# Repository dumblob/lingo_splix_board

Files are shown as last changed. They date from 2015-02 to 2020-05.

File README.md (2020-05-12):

# Lingo Splix Board

A brand new deeply ergonomic slim keyboard - HW &amp; SW

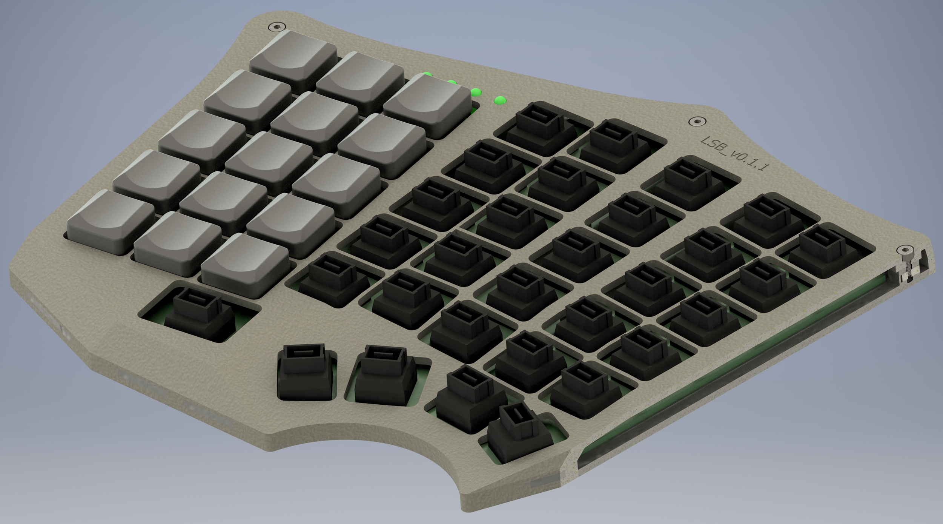
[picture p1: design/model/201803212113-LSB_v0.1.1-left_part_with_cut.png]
left part with a cut


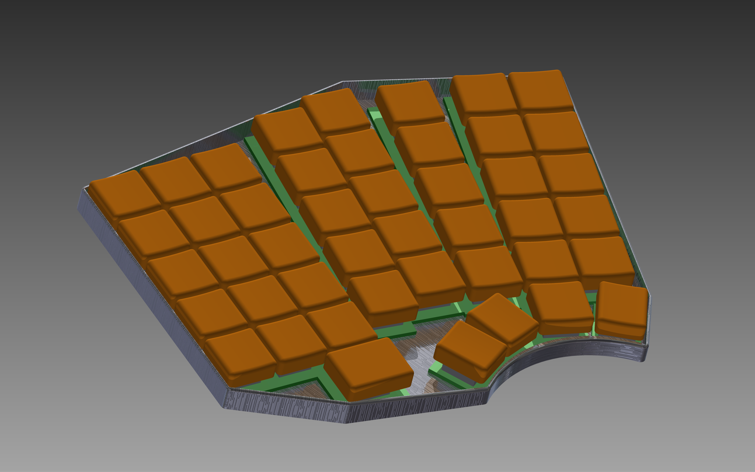
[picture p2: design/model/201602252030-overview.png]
overview_shot


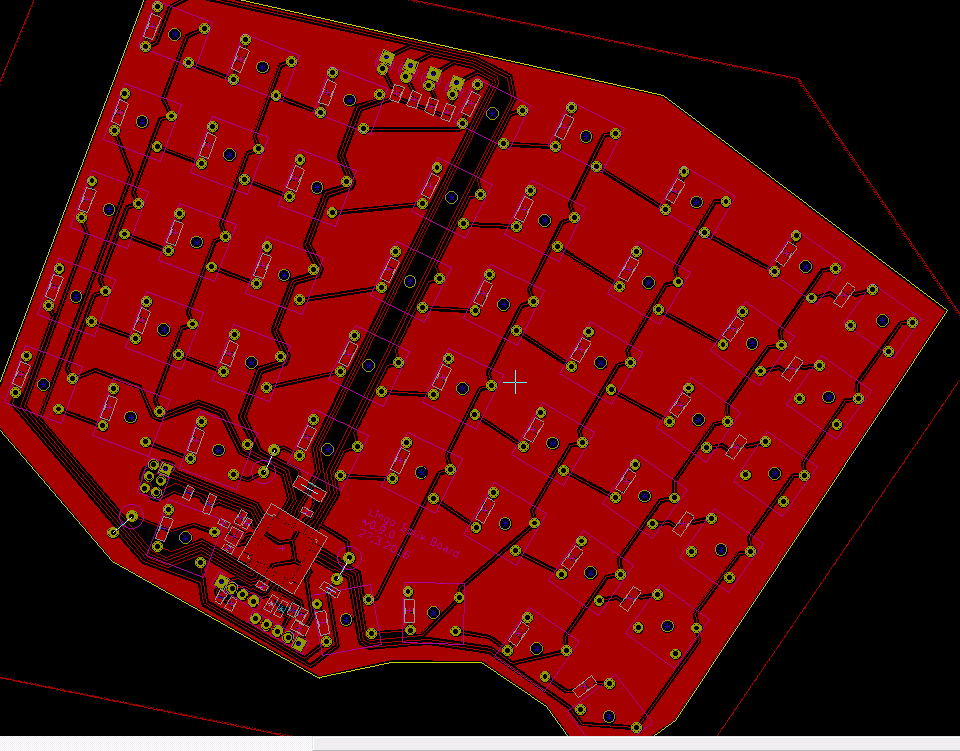
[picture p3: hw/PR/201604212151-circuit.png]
PCB left 201604212151


## Features

1. **Slim low-profile design**
1. **Split into 2 halfs** for outstanding ergonomy
1. **Portable** - easily foldable
1. **USB connection** - use it anywhere
1. [**Modern look**](https://www.youtube.com/watch?v=RVa64frZOLY) - please your heart
1. **Open Source** - never be dependent

<!-- from creators of ULKL -->
<!-- has certification from the Czech Ergonomy Association -->

## Progress

### Done

* design **animation**
    * https://www.youtube.com/watch?v=RVa64frZOLY
* design **sketch**
    * [LSB sketch 201507181700](design/model/201507181700-overview.png )
    * [LSB sketch 201507181701](design/model/201507181701-overview.png )
    * [LSB sketch 201602232051](design/model/201602232051-overview-no_caps.png )
    * [LSB sketch 201602232052](design/model/201602232052-overview.png )
    * [LSB sketch 201602232053](design/model/201602232053-overview.png )
    * [LSB sketch 201602252030](design/model/201602252030-overview.png )
    * [LSB sketch 201803212113 with a cut](design/model/201803212113-LSB_v0.1.1-left_part_with_cut.png )
    * [LSB sketch 201803212113 mirrored with a cut](design/model/201803212113-LSB_v0.1.1-left_part_with_mirrored_cut.png )
* sump **sketch**
    * https://www.youtube.com/watch?v=kU6nasYpbfk
    * [sump sketch left 201602252030](hw/PR/201602252030-sump.png )
* sump **3D print**
    * [sump left 201604081601](hw/PR/201604081601-left_sump_3D_printed.jpg )
    * [sump left 201604081603](hw/PR/201604081603-left_sump_3D_printed.jpg )
* **PCB** circuit scheme
    * [PCB left 20150720170901](hw/PR/20150720170901-screenshot.png )
    * [PCB left 20150720170926](hw/PR/20150720170926-screenshot.png )
    * [PCB left 20160213212414](hw/PR/2016-02-13_212414-screenshot.png )
    * [PCB left 20160228174205](hw/PR/20160228174205-circuit.png )
    * [PCB left 20160228174213](hw/PR/20160228174213-circuit.png )
    * [PCB left 201604212151](hw/PR/201604212151-circuit.png )
    * [PCB left 201604212153](hw/PR/201604212153-circuit.png )
    * [PCB left 201604212154](hw/PR/201604212154-circuit.png )

### TODO

* contact P. Jakoubek, D. Kolibáč, and L. Hejkal regarding the plastic parts of scissor switches (injection moulding into a steel/aluminium mold?)
* choose a better fitting HW license (similar to MIT and CC BY-SA 4.0, but with a notion about HW patents in a way, that anyone using this or derived work can't be sued)
* investigate double-trackpoint/point_stick placement - (un)mountable?, each half it's own and fixed?, 90°-rotated thumb micro-switches on the side?
* marketing (Student Agency - no place for keyboard; ...)
* add numeric keyboard to be successful on market

## Remarks

* use ATmega128A (QFP-64) or ATmega64A (TQFP-64)
* wrong fuse calculation might temporarily "brick" an Atmel uC (see [Engbedded Atmel AVR Fuse Calculator](http://www.engbedded.com/fusecalc/ ))
* *TWI* (Two Wire Interface) on Atmel is *I2C*
* SW USB circuit https://metalab.at/wiki/Metaboard
* 1-wire design guide PDF
* silicon rubber keys are for sale (http://sk.quad-ind.com/silikonove-klavesnice/ , http://www.unipad.cz/index.php/cs/silikonove-klavesnice)
* high-quality plastic manufacturing is affordable (price, time, quality) e.g. at http://www.shapeways.com/ (USA & Europe factories)
* for 3D printing use the most high quality PLA available (see the *arm-netbook* mailing list at phcomp.co.uk): [Faberdashery](http://www.faberdashery.co.uk/tag/pla/ )

## Links for inspiration

* similar keyboard, but done in a megalomaniac way: http://www.key64.org/
* similar keyboard, but done in a yet more megalomaniac way: http://www.keyboard.io/
* similar keyboard, with high switches, but using the same design process as we did (it's unbelievable their design is from 2013, our from 2008, but we didn't share anything :open_mouth:): http://habrahabr.ru/post/177347/
* similar keyboard, but older and from Japan (it's interesting as our design was done completely independently and we discovered this Japan keyboard first in 2020): http://xahlee.info/kbd/Japan_keyboard_layouts.html (look for *jp keyboard layout jis x6004 60014*)
* ZX81 USB kbd: http://blog.tynemouthsoftware.co.uk/2012/02/arduino-based-zx81-usb-keyboard.html
* IBM model M with USB: http://www.schatenseite.de/dulcimer.html?L=2
* IBM model M with USB: http://mg8.org/rump/
* Commodore 64 (C64) USB kbd: http://symlink.dk/projects/c64key/
* Mini Keyboard with Trackpoint: http://geekhack.org/showwiki.php?title=Island:4917&do=comments&page=83
* 3D printed keyboard: http://deskthority.net/workshop-f7/katy-keyboard-or-k80cs-key80-contoured-split-t8524.html
* Apple keyboard mod to NKRO + teensy: http://deskthority.net/viewtopic.php?f=7&t=1067
* SW USB implementation: http://www.obdev.at/products/vusb/index.html
* HW keyboard matrix explained in detail: http://blog.komar.be/how-to-make-a-keyboard-the-matrix/
* how to remove the old yellowish tint: http://retr0bright.wikispaces.com/
* TrackPoint history: https://news.ycombinator.com/item?id=9437780
* TrackPoint creator's collection of human interface devices: http://research.microsoft.com/en-us/um/people/bibuxton/buxtoncollection/default.aspx
* TrackPoint creator's notes about TrackPoint: http://research.microsoft.com/en-us/um/people/bibuxton/buxtoncollection/detail.aspx?id=60
* round plastic circles for index fingers mimicking a gliding TrackPoint

## Wishlist features

* selection from different variants (perhaps configurable)
    * Standard (full-featured big keyboard for power users)
    * Standard Wireless
    * Mini (cut-down version for portability and presentation)
    * Mini Wireless
* both halfs
    * wired (wire spool)
    * wireless (working with Android out of the box)
        * Mini ZigBee / CC2530 Module; HC-06 Arduino Bluetooh Bee; XBee; Bluetooh Bee HC-05 Wireless Bluetooth; Geeetech XBee 2mW Wire Antenna
        * HID for Bluetooth dongles in USB: http://anselm.hoffmeister.be/computer/hidclient/index.html.en
* fixture/handle/hinge to fix both halfs together in a space-saving manner
* backlit
* backlight (adjustable)
* anti-slippery stands (perhaps sucking disks)
* maybe water-proof

## Contributors

* Jiri Pacner (HW design)
* Itchy (HW design feedback)
* Pavel Pacner (3D models, media)
* Jan Pacner (initial idea, initial design, SW)
* *You* (you're more than welcome to join us!)

## Licensing

The following licenses apply if not stated otherwise:

* The SW part is under *MIT* (see `sw/LICENSE`).
* The HW part is under *CC BY-SA 4.0* (see `hw/LICENSE`).
* The rest is under *CC BY-SA 4.0* (see `design/LICENSE`).

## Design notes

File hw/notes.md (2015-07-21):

1) Mrkni na formaty, materialy a veskere dalsi pozadavky pro design desky na http://imall.iteadstudio.com/open-pcb/pcb-prototyping.html (po kliknuti na "add to cart") - budeme to s nejvyssi pravdepodobnosti vyrabet u nich. Mimochodem, az budes pridavat soucastky do vykresu, tak se nejprve mrkni, zdali je nemaji primo na http://imall.iteadstudio.com/electronic-components.html , protoze oni by je tam mohli ihned profesionalne osadit za minimalni priplatek. Tim znatelne zvysujeme sanci na oziveni a snizujeme vlastne cenu, protoze kdybychom kupovali soucastky zvlast, vyjde to nakonec urcite draz. Takovouhle https://openalt.org/led-logo-openaltu/ s nimi mame zkusenost my.

2) Jako cip s nejvyssi pravedpodobnosti pouzijeme bud ATmega64A (TQFP-64) nebo ATmega128A (QFP-64). Dokumentace k fixne danym pinum naleznes primo na strankach Atmelu (ostatni piny, tj. ty, ktere budou pripojene ke spinacum na klavesnici, si muzes navrhnout jak chces). Pouzdra jsou uvedena v zavorkach - tedy TQFP-64 a QFP-64. Prednost ma ATmega128A, protoze to ma dvojnasobne velke oboje dvoje nejdulezitejsi pameti (SRAM a Flash).

2) Budes tam muset zakomponovat obvody pro softwarove USB, konkretne https://metalab.at/wiki/Metaboard .

3) Urcite zacni s https://github.com/geekhack-org/kicad-library - hosi z Geekhacku na tom makaji jiz mnoho let. Take mrkni na "Why not use a Teensy" na http://www.ladyada.net/products/atmega32u4breakout/ , abys na takovehle "prkotiny" pri navrhu myslel. Kdyby te to kresleni fakt chytlo, tak pro inspiraci urcite doporucuji Adafruit https://learn.adafruit.com/ a jejich clanky/navody na pouziti a vyrobu jejich produktu.

4) Kazda polovina klavesnice musi pocitat s 15 GPIO piny - tzn., nelze pouzit "hloupe zapojeni podle radku a sloupcu", nybrz je nutno tlacitka zapojit do ctvercove matice (plus minus jeden radek/sloupec v pripade licheho cisla jako napr. 15=7+8), aby se setrilo mnozstvi GPIO pinu.

5) Nezapomenout na nejake LED kontrolky vyjma CapsLock, tedy zbyva pouze Pause, NumLock a mozna Fn. Lze je umistit kamkoliv, ale je pekne je mit "na ocich" - vyhnul bych se umistovani primo ke klavesam, protoze pokud si na klavesnici namapuji jiny layout, tak su v haji). Kazda LED ma vlastni GPIO, ale lze je "multiplexovat" pres opacna napeti pomoci Charlieplexing (viz wikipedia) - jak to navrhnes je na tobe (s napetim a odberem by nemel byt problem - kdyztak zapoj kazdou ledku do vlastniho portu [PORTA, PORTB, PORTC, PORTD...], protoze kazdy port byva napajeny zvlast, takze piny na jednom portu maji spolecny zdroj a tedy v pripade velkeho proudu pres piny na jednom portu lze odpalit cely port, tzn. vsechny piny - viz. blokovy diagram v dokumentaci). Pro jistotu ale spocitej, kolik ledek muzes na ten tvuj obvod maximalne zapojit a rozsvitit naraz (tj. nejhorsi pripad) a pokud se to bude blizit maximalnimu proudu skrze MCU (microcontroller unit, tedy Atmega), tak radeji pred kazdou ledku dej tranzistor, ktery ji bude pouze zapinat a privadet k ni napeti zvlast z nejakeho externiho spolecneho zdroje (coz bude USB - viz. specifikace).

6) Premyslet nad umistenim trackpointu (byvaji docela objemne a podstavce dost vysoke :cry:). Kolik bude potreba dratu/cesticek pro kazdy trackpoint?

Jinak take muzes nahodne udelat nejake video z toho jak kreslis (klidne i s komentarem - i kdyz nebude anglicky, tak je vitany), aby pote bylo co vystavovat (vsak vis, ze bez obrazku a videa dneska projekt proste neexistuje :( ).

Jednou z mych prvnich myslenek bylo, abys pri navrhu nezapomnel, ze obe poloviny te klavesnice budou muset byt necim propojeny (a tedy kazda mit v sobe vlastni cip - jedna z nich muze byt s vyrazne slabsim cipem, ale ja bych klidne na obe dal ten samy a ty 3 dolary rozdilu moc neresil; ani spotrebu zatim moc neresime :) ) - minimum jsou dva kabely(pro 1-wire protokol s power over line - napr. MicroLAN), kdy datovy kabel je pripojeny na jeden GPIO a k tomu zvenci pres nejaky maly obvudek (minimalne diodu a nejaky rezistor bych tipnul) k tomu datovem pripojis i napajeni a pak pridas druhy kabel, coz je zem. Ale radeji tam navrhni rovnou ctyri kabely pro I2C - tzn. dva kabely pripojene na TWI piny z te Atmegy (tusim pres pull-up rezistory - ale projdi dokumentaci - treba budou uz v cipu a na desce by byly zbytecne) a pak samostatne napajeni a posledni zase zem.

K tomuto vsemu najdes schemata na netu - hledej Atmega nebo AVR - vetsina navodu na obvody je univerzalnich pro jakoukoliv Atmegu.

vim: set wrap:

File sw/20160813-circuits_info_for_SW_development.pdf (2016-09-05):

–
–

–

Shrnuti zapojeni pro programatora:

zakladni info:

na hlavni casti (prava cast) klavesnice je pouzita Atmega 16A druha cast obsahuje Atmegu 8

nastaveni mikrokontroleru:

vnitrni piny nastavit jako input (vyuziti vnitrnich pull-up jako omezeni sumu)

rozlozeni pinu Atmega 16A:

1 - MOSI
2 - MISO
3 - SCK
4 - RST
5 - +5V
6 - GND
7 - crystal
8 - crystal
9 - not connected
10 - not connected
11 - not connected
12 - key input
13 - key input
14 - key input
15 - key input
16 - key input
17 - +5V
18 - GND
19 - SCL
20 - SDA
21 - USB data +
22 - USB data -
23 - not connected
24 - not connected
25 - not connected
26 - not connected
27 - +5V
28 - GND
29 - not connected
30 - key output
31 - key output
32 - key output
33 - key output

34 - key output
35 - key input
36 - LED 1
37 - LED 2
38 - +5V
39 - GND
40 - LED 3
41 - LED 4
42 - key output
43 - key output
44 - key output

rozlozeni pinu Atmega 8:

1 - key output
2 - not connected
3 - GND
4 - +5V
5 - GND
6 - +5V
7 - crystal
8 - crystal
9 - key input
10 - key input
11 - key input
12 - key input
13 - key input
14 - key output
15 - MOSI
16 - MISO
17 - SCK
18 - +5V
19 - not connected
20 - not connected
21 - GND
22 - key output
23 - key output
24 - key output
25 - key output
26 - not connected
27 - SDA
28 - SCL
29 - RST
30 - key input
31 - key output
32 - key output

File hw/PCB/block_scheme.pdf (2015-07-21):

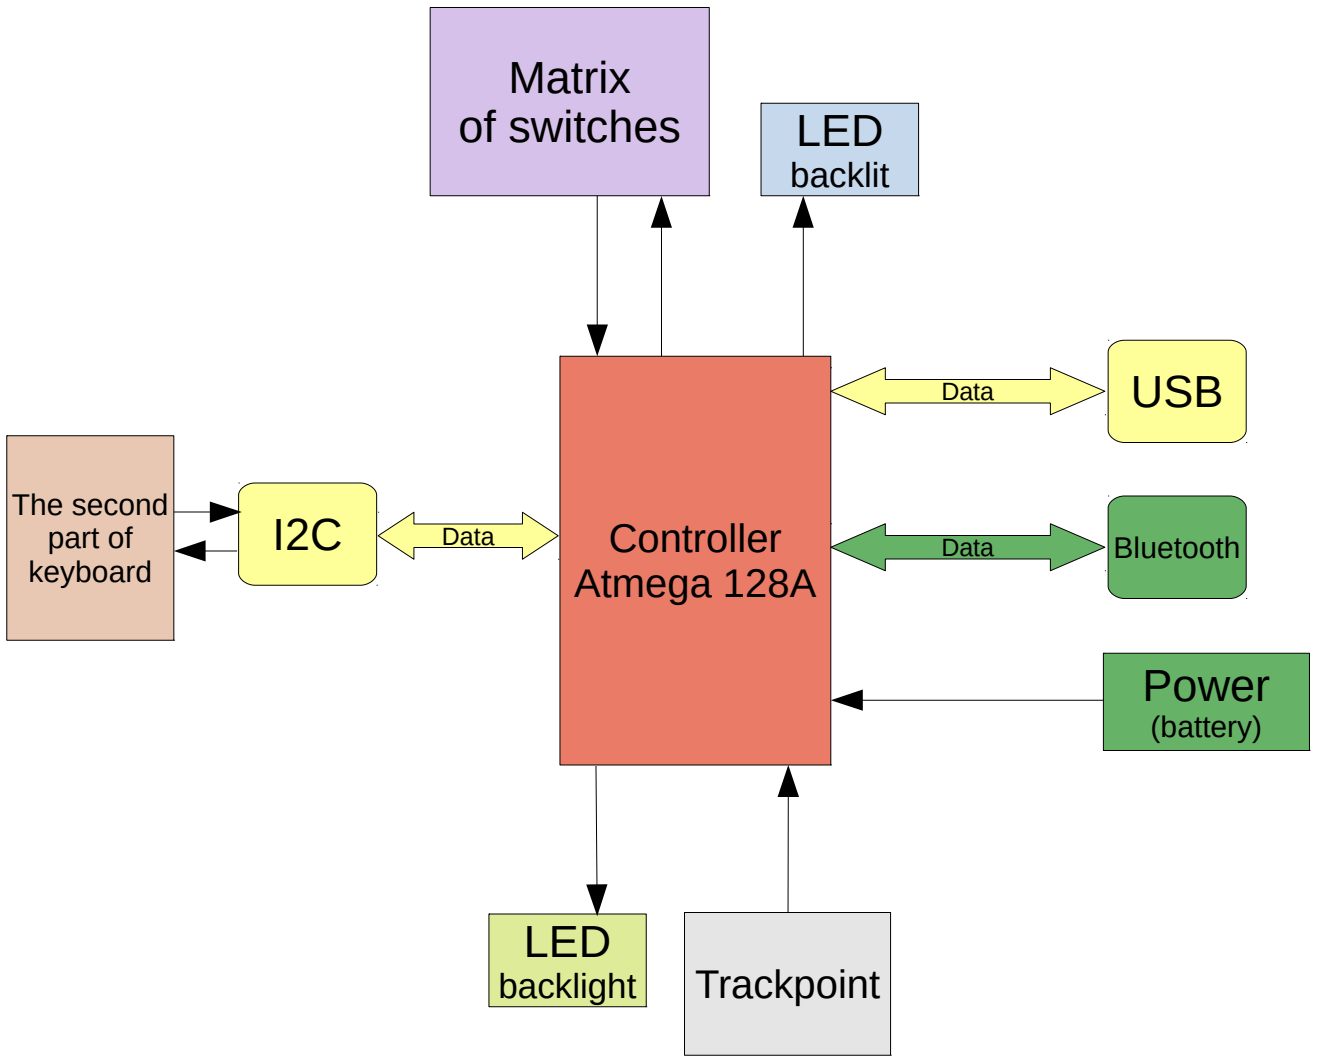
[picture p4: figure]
Controller Atmega 128A; Data; USB; Bluetooth; Power (battery); The second part of keyboard; Trackpoint; LED backlit; Matrix of switches; LED backlight

- for wireless version
- maybe next generation

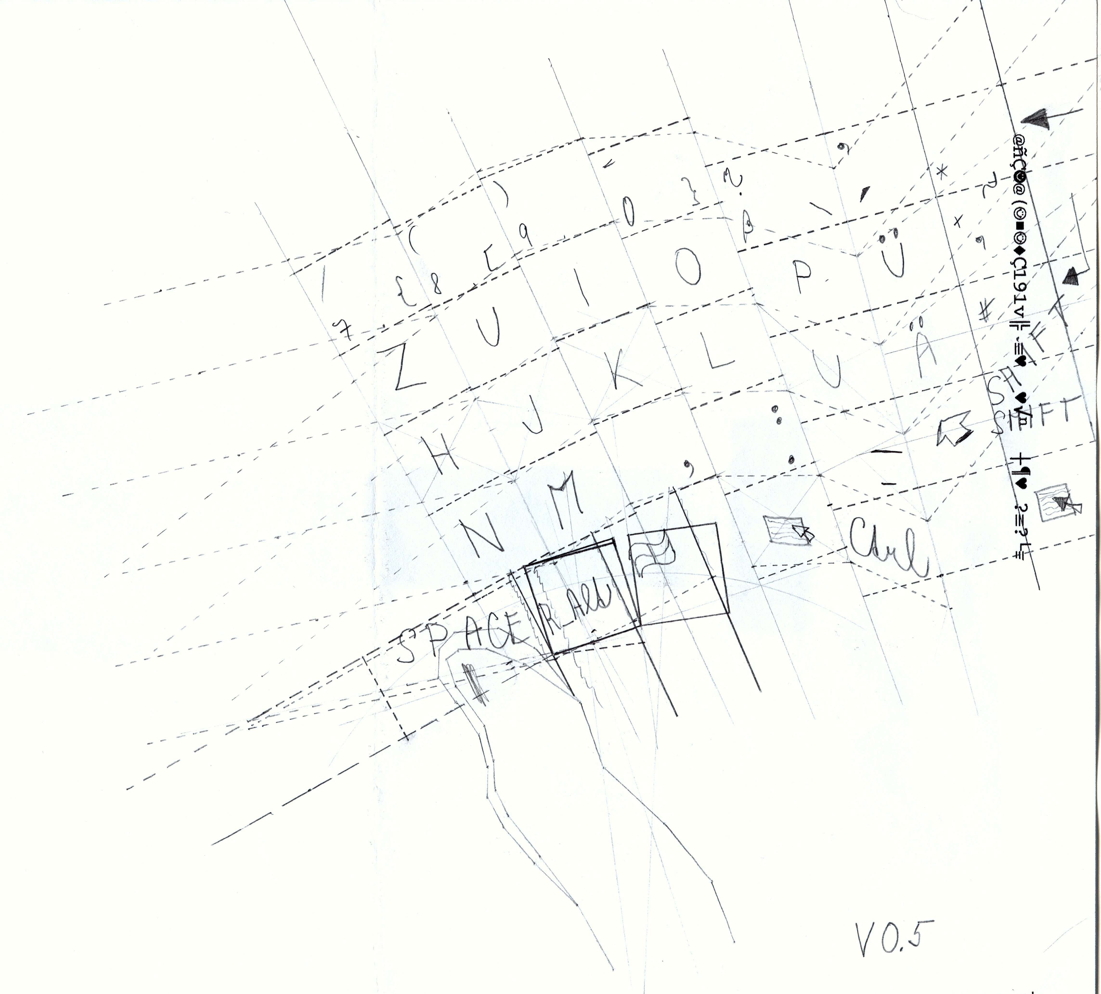
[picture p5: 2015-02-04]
design/evolution/v0.5_kbd-s.jpg

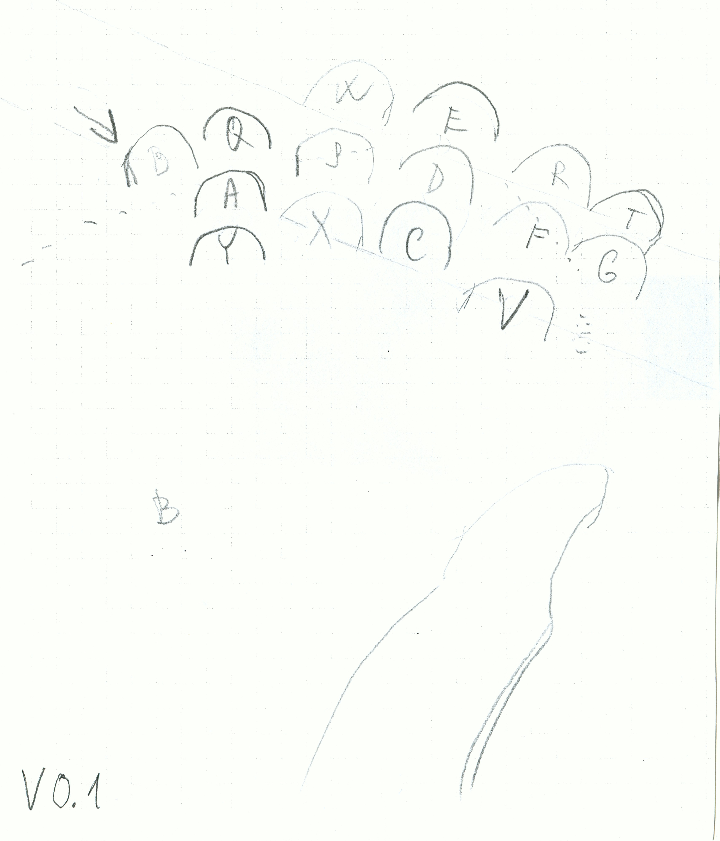
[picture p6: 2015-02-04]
design/evolution/v0.1_kbd-s.jpg

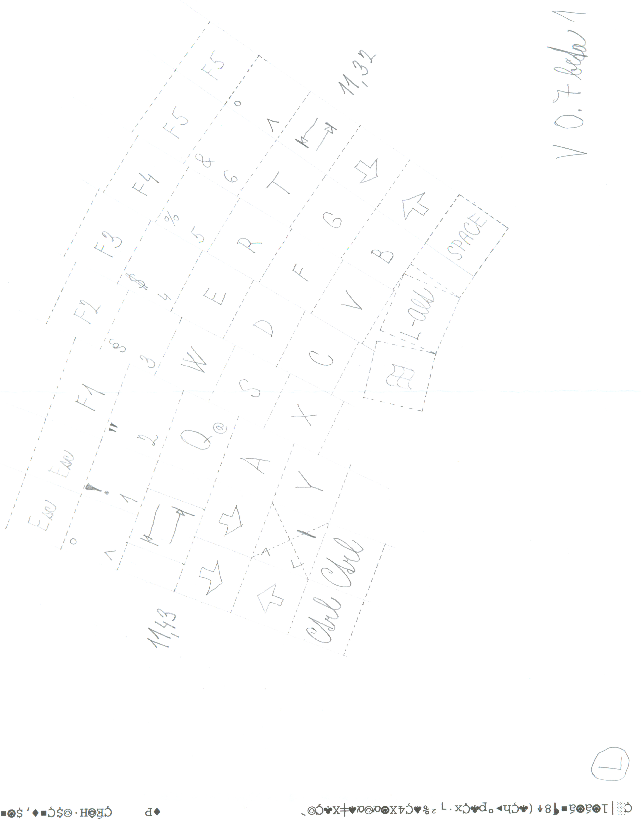
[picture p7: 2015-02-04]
design/evolution/v0.7beta1_kbd_left-s.jpg

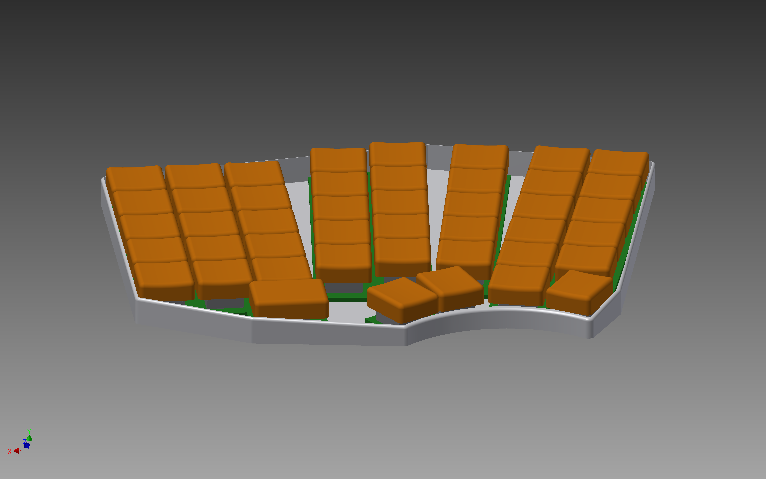
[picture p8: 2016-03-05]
design/model/201602232052-overview.png

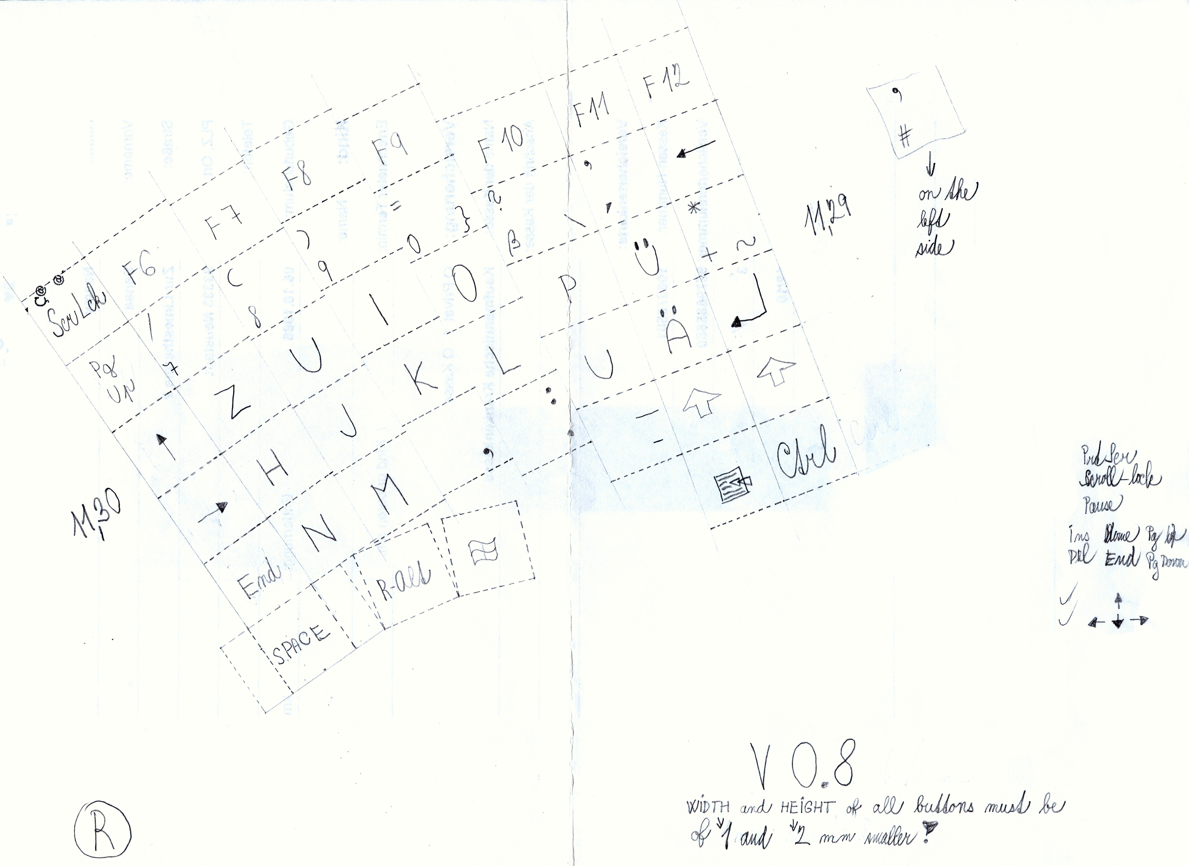
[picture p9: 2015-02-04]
design/evolution/v0.8_kbd_right-s.jpg

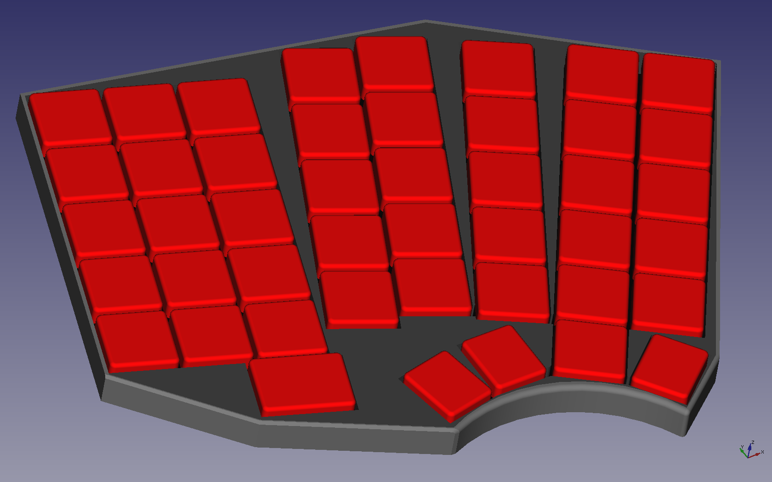
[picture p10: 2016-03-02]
design/model/2016-01-20_20:01:04-overview.png

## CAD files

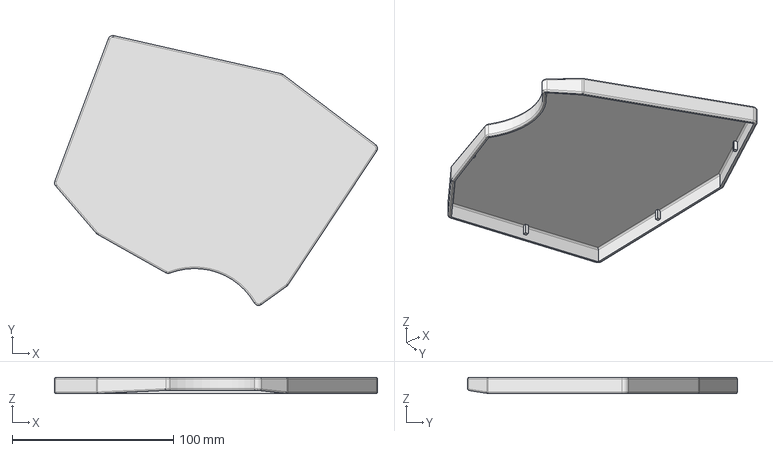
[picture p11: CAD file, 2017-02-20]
hw/scaffold/sump-left-v0.9.1.stp
200.5 x 167.5 x 10.0 mm

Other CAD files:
hw/scaffold/sump-right-v0.9.0.stl
hw/scaffold/sump-left-v0.9.0.stl

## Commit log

2015-02-04 change: file structure of the project repository
    add: all the hand-drawn designs
    add: non-SW and non-HW license
    add: hints for making HW and SW for keyboards (hex keycodes, kbd uC datasheet)
    add: pictures of an old attempt to remake an old keyboard to a split-keyboard
    add: pictures of low-profile Alps switches (meant to be used for the construction of a prototype)
2015-02-04 add: todo item - contact professionals regarding plastic moulding
2015-02-13 add: notion of trackpoint to TODO
    add: notes/hints for HW PCB layout design
2015-02-14 add: important notes about LEDs on PCB
2015-07-21 add: model screenshots
    add: preliminary HW circuit design screenshots
    add: HW circuit block scheme
2015-07-26 add: preliminary circuit schemes (kbd_ergo and kbd_ergo-USB)
    add: source file for the block scheme
    [kbd_ergo-USB.sch, kbd_ergo.sch]
2015-08-05 minor: change wording in wireless requirements
2015-08-08 add: pictures - modelling of the keyboard in a CAD
2015-08-20 add: link to a 3D printed keyboard
2016-01-02 add: sump sketch
    [sump.FCStd]
2016-01-09 add: notion about trackpoint/pointstick side-buttons
    minor: update year
2016-01-09 add: links about TrackPoint and human interface devices
2016-02-14 add: screenshot of half-finished HW circuit
2016-03-02 add: circuit export pictures
2016-03-04 add: full circuit picture - left part
2016-03-06 change: hide the circuit screenshot, because it is quite wrong
2016-04-02 add: preliminary left sump sketch without locks
    add: list of brainstormed marketing names for keyboards
    [sump-left-v0.9.0.stl]
2016-04-03 add: right and left beta sumps
    add: notion about numeric keyboard, being a requirement for success on a market, to README
    [sump-left-v0.9.0.stl, sump-right-v0.9.0.stl, sump.FCStd]
2016-04-03 change: rename sump-right STL to sump-left (sump-right does not exist yet)
    [sump-left-v0.9.0.stl, sump-right-v0.9.0.stl]
2016-04-19 change: add current PCB scheme of the left keyboard and remove the old one
    minor: fix README
    [kbd_ergo-USB.sch, kbd_ergo.sch, kbd_ergo_atmega16a.sch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]
2016-04-23 add: right sump scaffold
    add: current PCB screenshots
    [sump-right-v0.9.0.stl]
2016-04-23 add: photos of the first 3D-printed prototype of left sump
2016-09-05 add: description of circuit info for SW development
    add: link about setting up AVR
2016-09-06 add: notion about gliding index finger circle mimicking TrackPoint
2017-02-20 add: photos of a professionally produced PCBs (no components placed yet)
2017-02-20 add: updated version of the sump (fixing the inappropriate auto-added 3D print support for holdbacks holding PCB)
    [sump-left-v0.9.1.stp]
